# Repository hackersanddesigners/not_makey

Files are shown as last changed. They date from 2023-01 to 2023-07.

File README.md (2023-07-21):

# not_makey

This repository describes how to manufacture a shield for the ESP32, and the code to program pins as resistive touch sensors that each send strings to a laptop over Bluetooth. It is programmed to send letters that correspond with PJ machine keycodes used in e.g. this workshop https://github.com/hackersanddesigners/interfacial-workout-23

On the board you can see which pins are connected to which letter. Pins without a letter are free to use for something else (e.g. sensors, LEDs), additional code can be written inside the sketch. 

To send a letter to the laptop: 
- connect laptop to bluetooth device "NOT_MAKEY" (esp and shield should be connected to a power source)
- open a textpad on the laptop
- touch a probe connected to one of the letter pins, and a probe connected to GND to send a letter via Bluetooth

## acknowledgments

* Joylab's Jay Silver & Erik Rosenbaum's *MakeyMakey board* [https://github.com/sparkfun/MaKeyMaKey](https://github.com/sparkfun/MaKeyMaKey)
* Manualbl's [repository on using ESP32 as Bluetooth Keyboard](https://gist.github.com/manuelbl/66f059effc8a7be148adb1f104666467)
* Jack Christensen's [moving average library](https://github.com/JChristensen/movingAvg)

# v2 via Aisler board house

## bill of materials v.2 

* an ESP32 WROOM devkit, e.g. [this one from Espressif](https://www.espressif.com/en/products/modules/esp32) €14,49 at [Reichelt](https://www.reichelt.nl/nl/nl/entwicklungsboard-esp32-wroom-32e-esp32devkitc32e-p341303.html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)
* mini usb programming cable e.g. [this one at kiwi](https://www.kiwi-electronics.com/nl/microusb-kabel-usb-a-naar-micro-b-15cm-3240?search=usb-A%20naar%20micro-b) €1,25
* 4x single row break-away female header strips (you need 4x a single row strips of 15 positions) e.g. [this one](https://www.reichelt.nl/nl/nl/vrouwelijke-connector-2-54mm-1x20-scheidbaar-vertind-fis-bl1-20-z-p283794.html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) at Reichelt €1,22 each
* 14x 22Mohm resistors e.g. [this one](https://nl.farnell.com/yageo/hhv-25jt-52-22m/res-22m-5-250mw-axial-metal-film/dp/1779371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) at Farnell €0,07 each. These can be hard to find in DIY shops you might need to look at Farnell, Mouser, or get some from China :(
* 14x (or more) MM dupont jumper wires to access the pins
* alligator clips to connect connective stuff to the board. 

## schematic

The schematic is the same

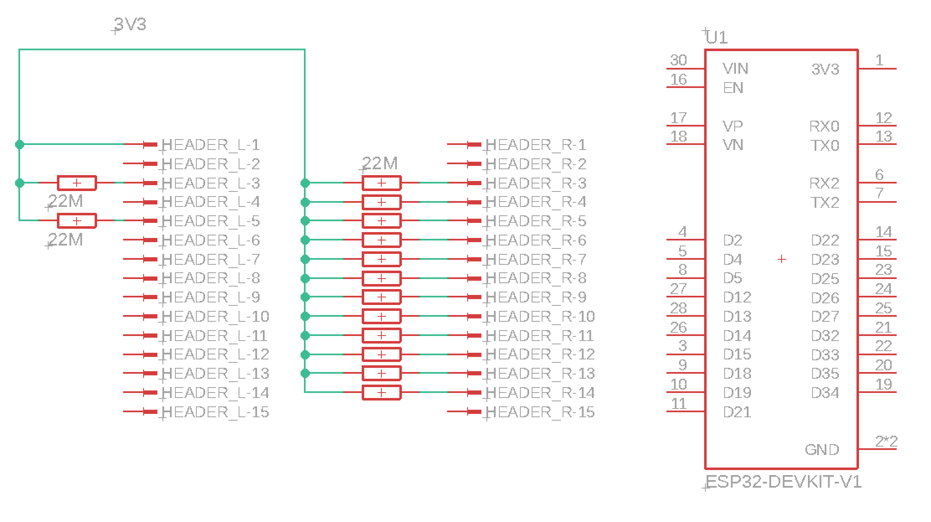
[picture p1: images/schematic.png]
schematic v2
 

## board design

The silkscreen is a bit more elaborate so you can see what character corresponds with which pin in the code.

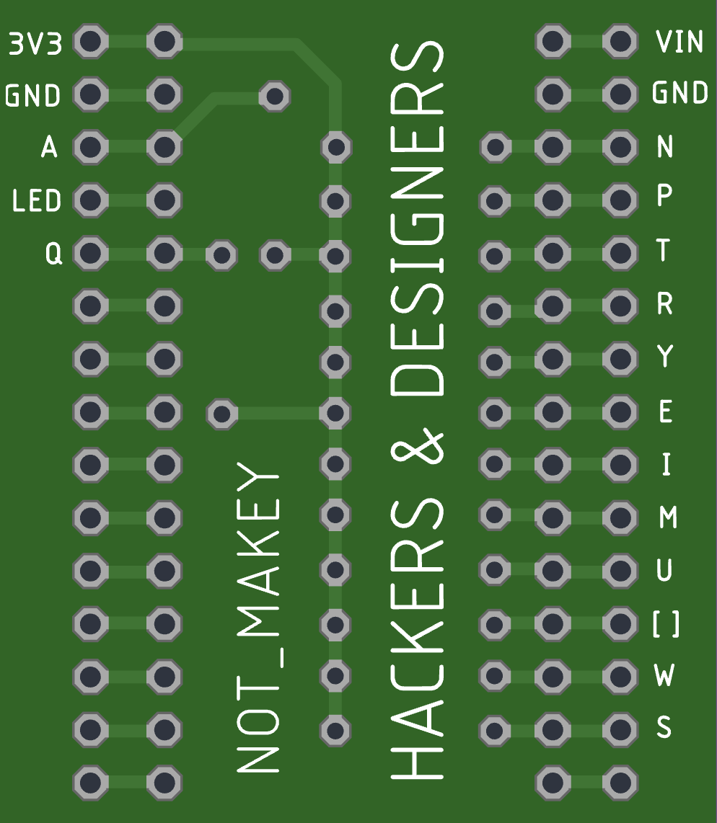
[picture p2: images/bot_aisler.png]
 

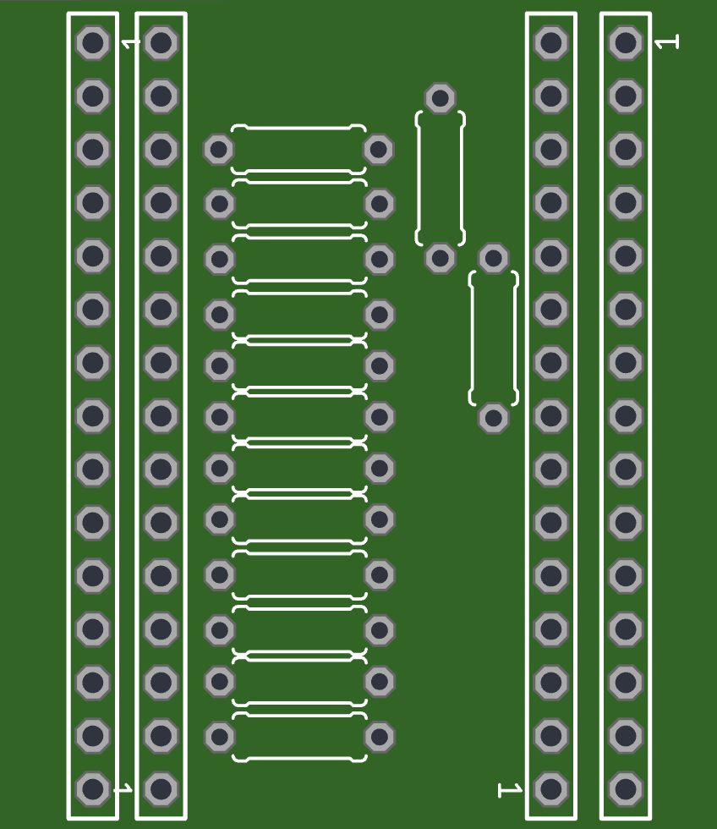
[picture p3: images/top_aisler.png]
 

## board house link

[https://aisler.net/p/JORJIJIP](https://aisler.net/p/JORJIJIP)

## soldering

For this board, you'll need to have the inner 2 connector rows facing down to connect to the ESP32 

The outer two connector rows are facing outward, to give access to the pins via jumper wires

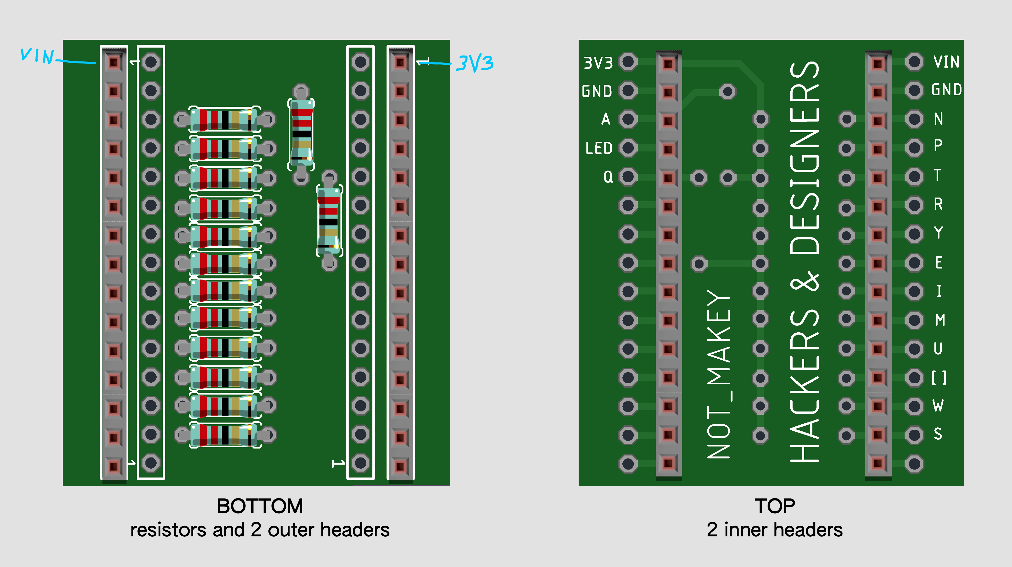
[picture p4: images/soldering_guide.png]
diagram with components in the right place


## programming the ESP

[Arduino code](./arduino/esp32_ble_makey_14probes/esp32_ble_makey_14probes.ino)

This program lets an ESP32 act as a keyboard connected via Bluetooth.
When a button attached to the ESP32 is pressed, it will generate the key strokes

In order to receive the message, add the ESP32 as a Bluetooth keyboard of your computer or mobile phone:

  1. Go to your computers/phones settings
  2. Ensure Bluetooth is turned on
  3. Scan for Bluetooth devices
  4. Connect to the device called "NOT_MAKEY" (you can change this name in the code)
  5. Open an empty document in a text editor
  6. Press the buttons attached to the ESP32 to generate different letters
 
If the probes don't respond too well you can troubleshoot and calibrate with simple code using the moving average filter and printing it to the serial. 

[Moving AVG testcode](./arduino/esp32_movingAVG_analogread/esp32_movingAVG_analogread.ino)

### Select the board

* Open Arduino preferences pane and paste the following URL in the box "Additional Boards Manager URLs"

```https://espressif.github.io/arduino-esp32/package_esp32_index.json```

* Open the Boards Manager. Go to Tools > Board > Boards Manager… 
* Search for "ESP32" and press install for "ESP32 by Espressif Systems"
* Go to > Tools > Board > ESP32 Arduino > ESP32 Devkit
* If it doesnt' show up, restart the Arduino IDE

### Compile the code to check libs are working

Compile to check if you have all the libraries. If not, check the console for troubleshooting. If necessary, install these: 

* MovingAVG library by Jack Christensen (via library manager)
* [BLE library](https://reference.arduino.cc/reference/en/libraries/esp32-ble-arduino/) (via library manger)
* [ESP32 libraries](https://github.com/espressif/arduino-esp32/tree/master/libraries) (I believe these are installed automaticallly with the ESP32 board files, so shouldn't give any problems).

### Testing 

* Connect the board to the computer with a USB data cable and upload the code
* Connect the ESP to the shield, taking care the orientation is correct. 
* Connect probes, e.g. jumper wires to one or two pins with a letter next to it
* Connect a laptop to the bluetooth device called "NOT_MAKEY" (name can be changed in line 63 in the code)
* Open a notepad on the connected laptop
* Test by touching a probe with one finger, while touching the 3V3 with the other finger. The principle is the same as makey makey, but here the resistors are connected as a pull-up resistor (keeps the signal high until a change is registered), so you touch one of the pins AND 3V3 (instead of one of the pins and GND as you would on the makey makey).

# Previous versions

## v1 via fablab

## tools

* Roland Modela MDX-20 with MODS for pcb production installed (only works in Chrome) modsproject.org

Note that this process doesn't require Gerber files, instead you need a 1000 DPI black and monochrome images of the bottom of the board, and separate files with holes and the board outline).

* Soldering station, solder, clippers

## bill of materials v.1 

* an ESP32 WROOM devkit, e.g. [this one from Espressif](https://www.espressif.com/en/products/modules/esp32) €14,49 at [Reichelt](https://www.reichelt.nl/nl/nl/entwicklungsboard-esp32-wroom-32e-esp32devkitc32e-p341303.html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)
* mini usb programming cable e.g. [this one at kiwi](https://www.kiwi-electronics.com/nl/microusb-kabel-usb-a-naar-micro-b-15cm-3240?search=usb-A%20naar%20micro-b) €1,25
* 2x single row break-away female header strips (you need 2x a single row strips of 15 positions) e.g. [this one](https://www.reichelt.nl/nl/nl/vrouwelijke-connector-2-54mm-1x20-scheidbaar-vertind-fis-bl1-20-z-p283794.html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) at Reichelt €1,22 each
* 14x 22Mohm resistors e.g. [this one](https://nl.farnell.com/yageo/hhv-25jt-52-22m/res-22m-5-250mw-axial-metal-film/dp/1779371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) at Farnell €0,07 each. These can be hard to find in DIY shops you might need to look at Farnell, Mouser, or get some from China :(
* 14 or more Alligator clips to connect your DIY buttons to the board

<img src="./images/breakaway-fem-header.png" alt="header" width="500"> 

*Break-away header strip*

## software & dependencies

* Arduino IDE: [www.arduino.cc](www.arduino.cc)
	* Install the board with the board manager: 
		* *esp32* by espressif
		* select board > ESP Arduino > ESP 32 Dev Module  
	* Install the following libraries: 
		* *movingAVG.h* by Jack Christensen
		* the other libs included in the code don't seem to need an install (perhaps come with ESP32 board definitions? > check)
* Eagle (if you want to edit or redesign the board)
* GIMP or photoshop (if you want to edit the milling files directly)

## manufacturing the shield

### prototyping setup

<img src="./images/wiring.png" alt="header" width="500"> 

### schematic v.1

<img src="./images/schematic.png" alt="header" width="600"> 

### board v.1 

<img src="./images/simple_boardlayout_bottom.png" alt="header" width="500"> 

### fabrication files for Roland modela MDX-20

####**Exporting the design from Eagle**

* exported as PNG images from Eagle at 1000 dpi in monochrome
	* MILLING - traces - exported layers: bottom, pads, via's
	* DRILLING - holes and board outline - exported layers: vias & 

####**Editing the images**

* resize images to 50% in photoshop (something happens in the export from eagle)

#####*Bottom_v1.png*

* deleted little bits and text with bucket tool
* added new text (that is not in mirror image :D) 

<img src="./fabrication/v0/bottom_v0.pnG" alt="header" width="400"> 

#####*Holes_v1.png* 

* Deleted the big 4 holes on top and bottom of the board, they're not needed but came with the footprint

<img src="./fabrication/v0/holes_v0.png" alt="header" width="400"> 

#####*Dimension_v1.png*

* manually drew a rectangle larger than the board outline to make sure the board dimension is visible in the image (otherwise it's right at the edge)

<img src="./fabrication/v0/dimension_v0.png" alt="header" width="400"> 

### milling the PCB

<img src="./fabrication/v0/modsprojectPCB_dimension.png" alt="header"> 

* Mill the [bottom.png file](./fabrication/bottom.png)
* Drill holes [cut.png file](./fabrication/cut.png)
* Mill outline [outline.png file](./fabrication/?????)
* Wash
* Test connections
* Make corrections

<img src="./images/top_milled.jpeg" alt="top, milled" width="400">

<img src="./images/bot_milled.jpeg" alt="bottom, milled" width="400"> 

### soldering

Solder resistors & connectors as per board layout

<img src="./images/soldered_bot.jpeg" alt="bottom, soldered" width="400">

<img src="./images/soldered_top.jpeg" alt="top, soldered" width="400">

## wishes based on v.1

* pads are very small, not handy. Add second row of connector pins instead? (saves space)
* bigger footprint for resistors (min .8mm drill holes, thicked pads)

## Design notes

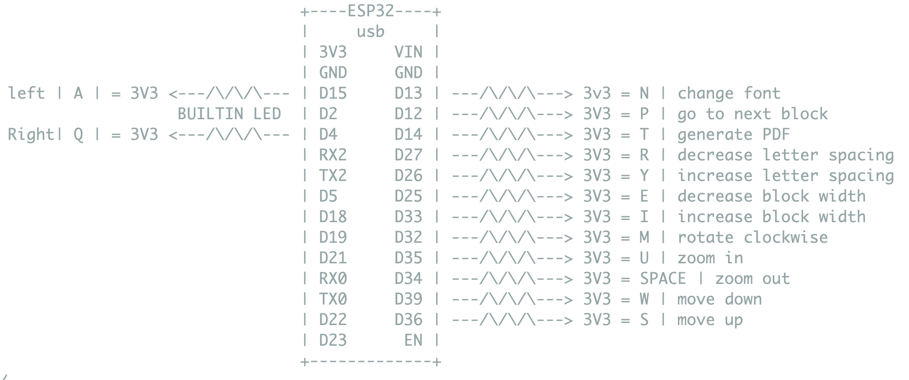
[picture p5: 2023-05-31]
images/diagram.png

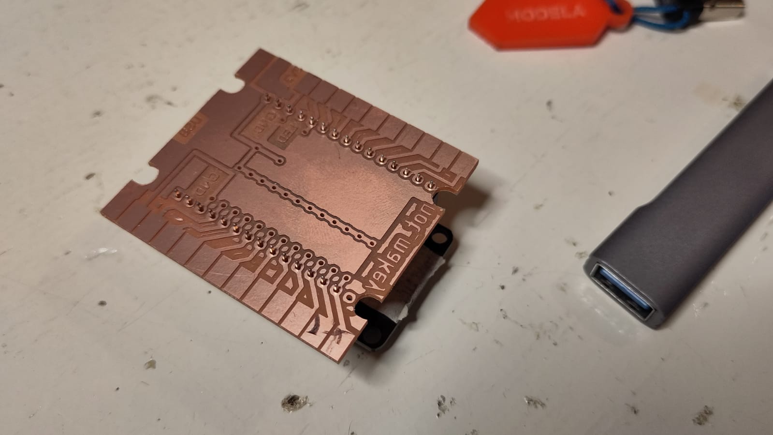
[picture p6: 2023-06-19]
images/top_milled.jpeg

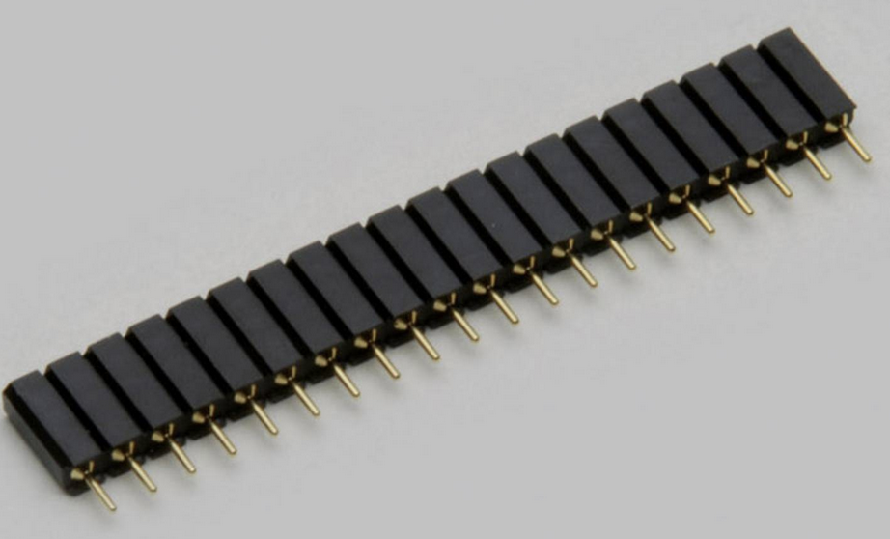
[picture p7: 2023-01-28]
images/breakaway-fem-header.png

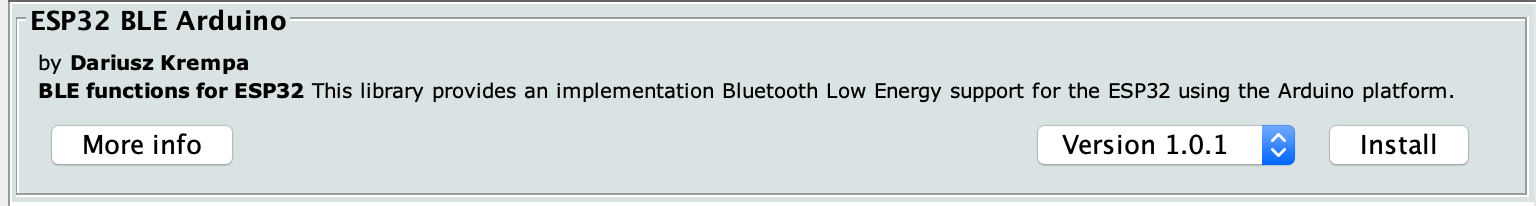
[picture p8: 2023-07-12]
images/lib-espBLE.png

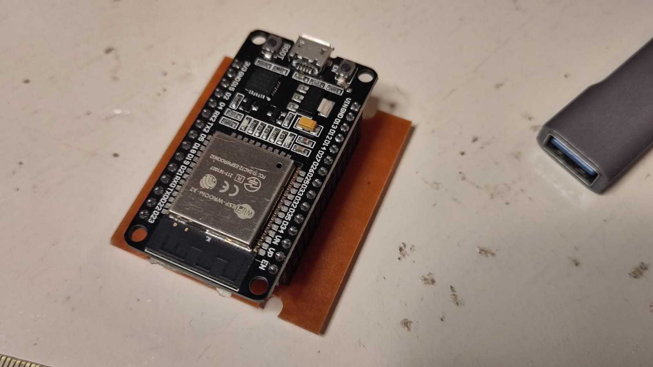
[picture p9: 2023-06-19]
images/bot_milled.jpeg

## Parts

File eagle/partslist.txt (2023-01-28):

Partlist

Exported from esp32_makey_shield.brd at 27/01/2023 16:15

EAGLE Version 9.6.2 Copyright (c) 1988-2020 Autodesk, Inc.

Assembly variant: 

Part        Value           Package                Library         Position (mil)        Orientation		Description

ADCPINS     TSW-115-07-G-S  TSW-115-XX-G-S         con-samtec      (460 918)             R90			15 pin female single row header 2.54 pitch      	
MOSTLYEMPTY TSW-115-07-G-S  TSW-115-XX-G-S         con-samtec      (1460 919)            R90			15 pin female single row header 2.54 pitch
R1          22M             0204/7                 rcl             (716 1416)            R180			22M ohm resistor (throughhole)
R2          22M             0204/7                 rcl             (716 1316)            R180			22M ohm resistor (throughhole)
R3          22M             0204/7                 rcl             (716 1216)            R180			22M ohm resistor (throughhole)
R4          22M             0204/7                 rcl             (716 1116)            R180			22M ohm resistor (throughhole)
R5          22M             0204/7                 rcl             (716 1016)            R180			22M ohm resistor (throughhole)
R6          22M             0204/7                 rcl             (716 916)             R180			22M ohm resistor (throughhole)
R7          22M             0204/7                 rcl             (716 816)             R180			22M ohm resistor (throughhole)
R8          22M             0204/7                 rcl             (716 716)             R180			22M ohm resistor (throughhole)
R9          22M             0204/7                 rcl             (716 616)             R180			22M ohm resistor (throughhole)
R10         22M             0204/7                 rcl             (716 516)             R180			22M ohm resistor (throughhole)
R11         22M             0204/7                 rcl             (716 416)             R180			22M ohm resistor (throughhole)
R12         22M             0204/7                 rcl             (716 316)             R180			22M ohm resistor (throughhole)
R13         22M             0204/7                 rcl             (1216 1416)           R0			22M ohm resistor (throughhole)
R14         22M             0204/7                 rcl             (1216 1216)           R0			22M ohm resistor (throughhole)
U1          ESP32-DEVKIT-V1 MODULE_ESP32_DEVKIT_V1 ESP32-DEVKIT-V1 (962 1014)            R0			ESP32-WROOM devkit (e.g. espressif)

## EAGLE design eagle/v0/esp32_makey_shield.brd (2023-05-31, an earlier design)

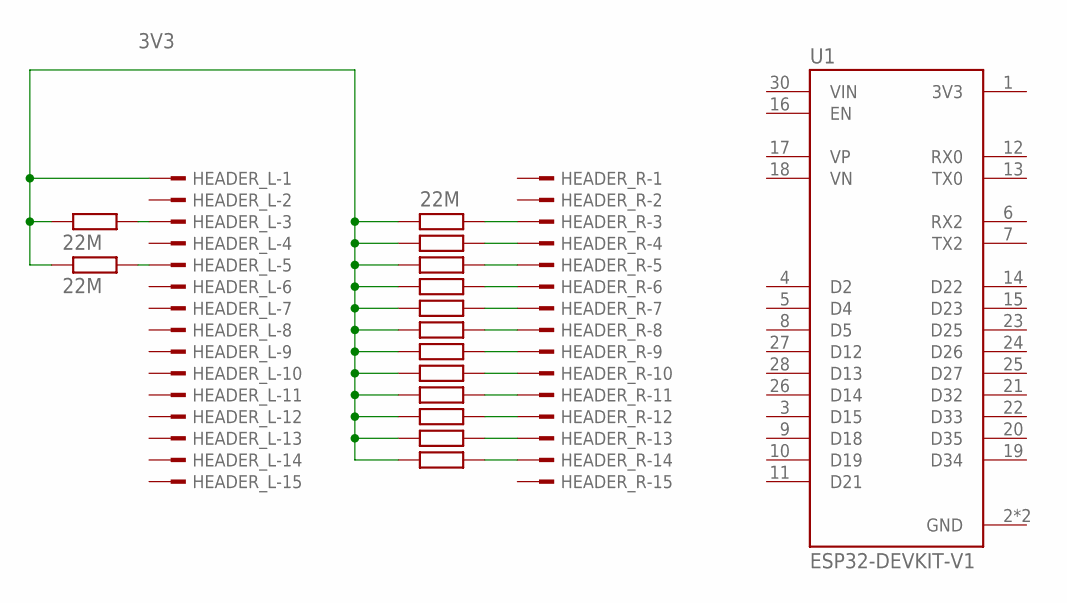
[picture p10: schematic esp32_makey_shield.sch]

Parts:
HEADER_L: TSW-115-07-G-S; TSW-115-XX-G-S
HEADER_R: TSW-115-07-G-S; TSW-115-XX-G-S
R1, R2, R3, R4, R5, R6, R7, R8, R9, R10, R11, R12, R13, R14: 22M; 0204/7
U1: ESP32-DEVKIT-V1; MODULE_ESP32_DEVKIT_V1

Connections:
3V3: HEADER_L.1, R1.1, R2.1, R3.1, R4.1, R5.1, R6.1, R7.1, R8.1, R9.1, R10.1, R11.1, R12.1, R13.1, R14.1
GND: U1.2 (GND), U1.29 (GND)
unnamed: HEADER_L.3, R13.2
unnamed: HEADER_L.5, R14.2
unnamed: HEADER_R.3, R1.2
unnamed: HEADER_R.4, R2.2
unnamed: HEADER_R.5, R3.2
unnamed: HEADER_R.6, R4.2
unnamed: HEADER_R.7, R5.2
unnamed: HEADER_R.8, R6.2
unnamed: HEADER_R.9, R7.2
unnamed: HEADER_R.10, R8.2
unnamed: HEADER_R.11, R9.2
unnamed: HEADER_R.12, R10.2
unnamed: HEADER_R.13, R11.2
unnamed: HEADER_R.14, R12.2

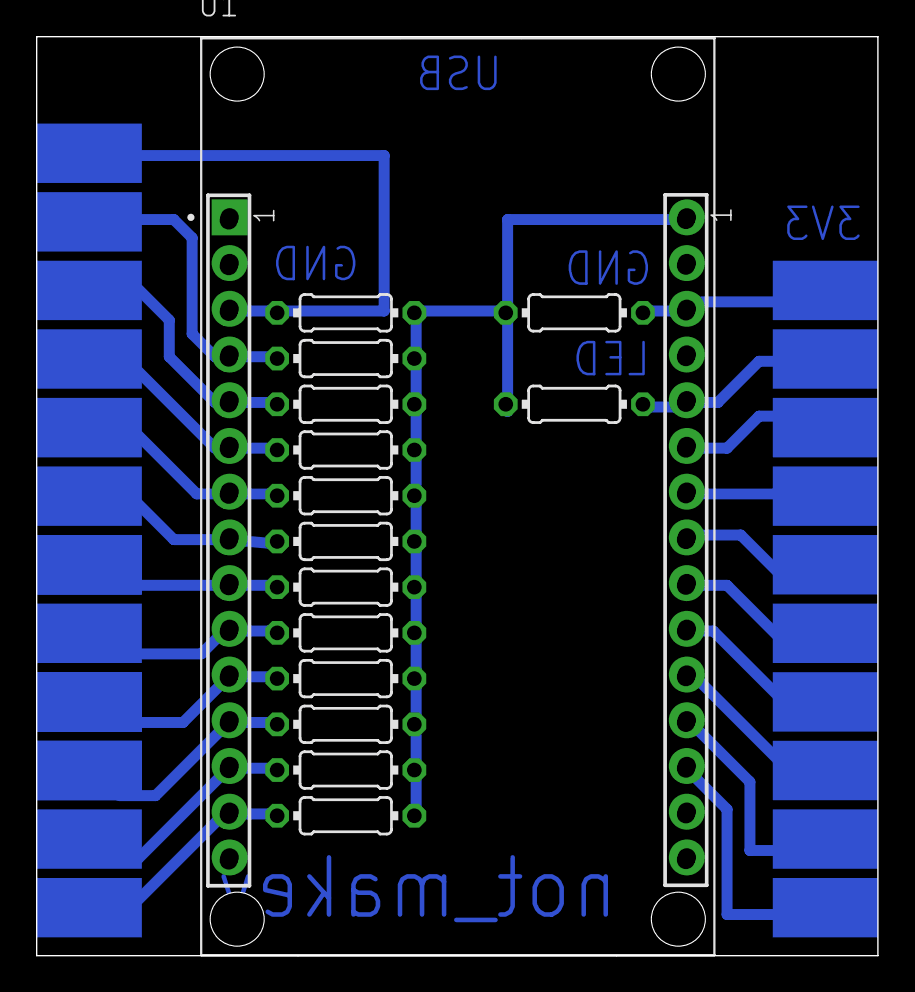
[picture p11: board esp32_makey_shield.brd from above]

Board: 2 copper layers, 46.7 x 51.1 mm, 17 parts (0 on the bottom side), 16 nets.

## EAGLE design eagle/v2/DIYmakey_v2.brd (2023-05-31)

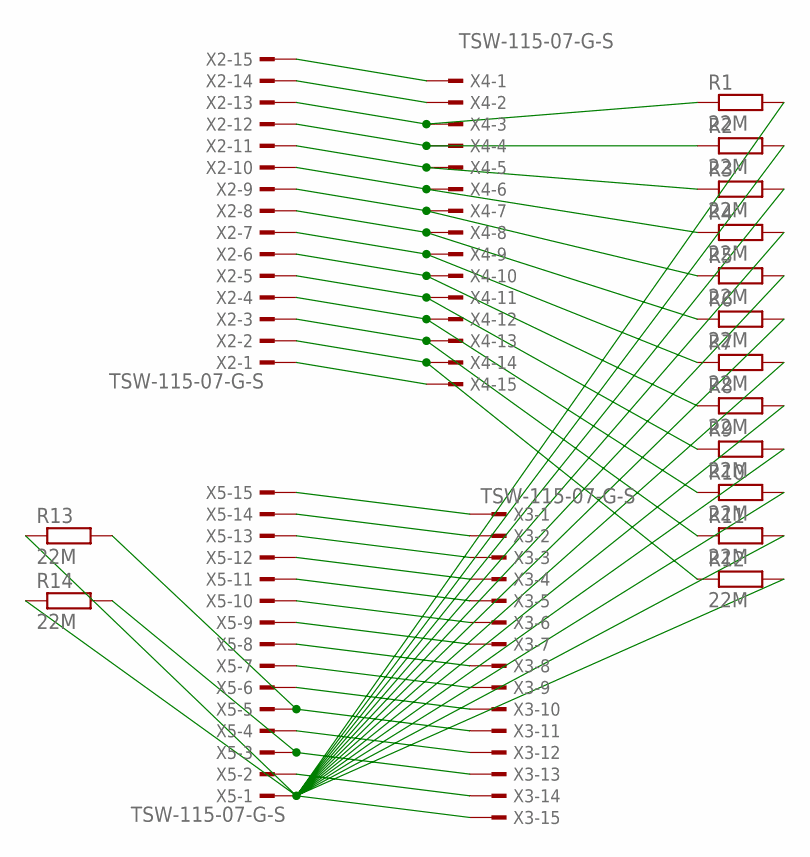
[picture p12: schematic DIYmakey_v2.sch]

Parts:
R1, R2, R3, R4, R5, R6, R7, R8, R9, R10, R11, R12, R13, R14: 22M; 0207/7
X2, X3, X4, X5: TSW-115-07-G-S; TSW-115-XX-G-S

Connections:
unnamed: X2.15, X4.1
unnamed: X2.14, X4.2
unnamed: R1.1, X2.13, X4.3
unnamed: R2.1, X2.12, X4.4
unnamed: R3.1, X2.11, X4.5
unnamed: R4.1, X2.10, X4.6
unnamed: R5.1, X2.9, X4.7
unnamed: R6.1, X2.8, X4.8
unnamed: R7.1, X2.7, X4.9
unnamed: R8.1, X2.6, X4.10
unnamed: R9.1, X2.5, X4.11
unnamed: R10.1, X2.4, X4.12
unnamed: R11.1, X2.3, X4.13
unnamed: R12.1, X2.2, X4.14
unnamed: X2.1, X4.15
unnamed: X3.1, X5.15
unnamed: X3.2, X5.14
unnamed: X3.3, X5.13
unnamed: X3.4, X5.12
unnamed: X3.5, X5.11
unnamed: X3.6, X5.10
unnamed: X3.7, X5.9
unnamed: X3.8, X5.8
unnamed: X3.9, X5.7
unnamed: X3.10, X5.6
unnamed: R13.2, X3.11, X5.5
unnamed: X3.12, X5.4
unnamed: R14.2, X3.13, X5.3
unnamed: X3.14, X5.2
unnamed: R1.2, R2.2, R3.2, R4.2, R5.2, R6.2, R7.2, R8.2, R9.2, R10.2, R11.2, R12.2, R13.1, R14.1, X3.15, X5.1

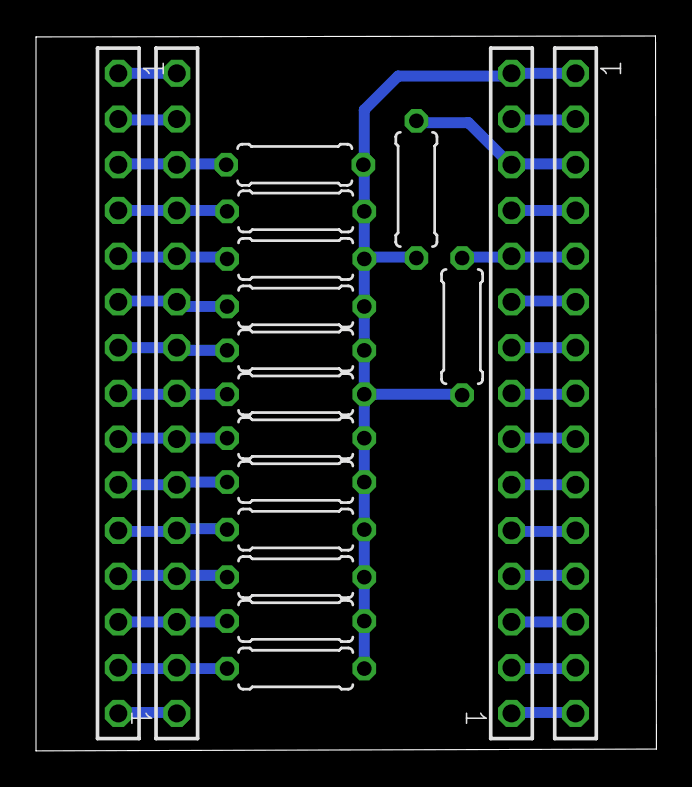
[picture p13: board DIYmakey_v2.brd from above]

Board: 2 copper layers, 34.5 x 39.7 mm, 18 parts (0 on the bottom side), 30 nets.

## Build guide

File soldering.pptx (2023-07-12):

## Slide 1

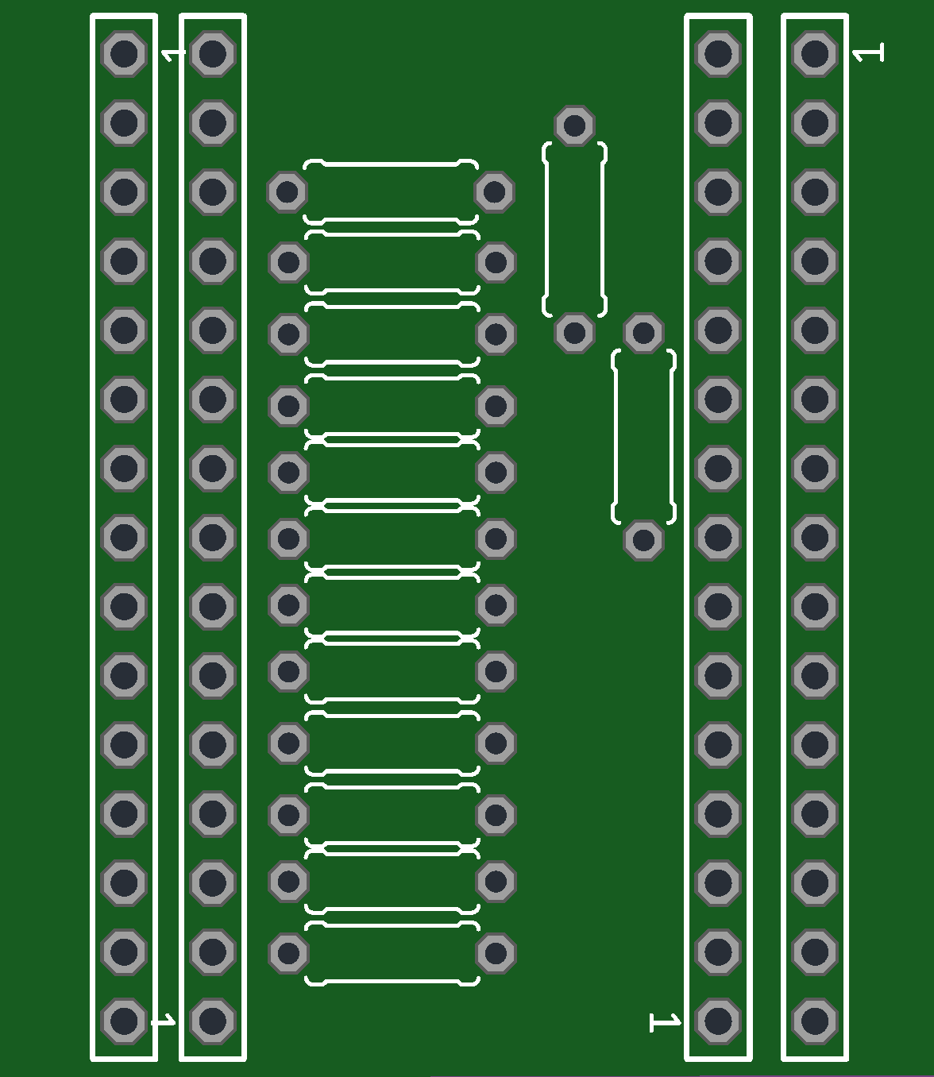
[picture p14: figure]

BOTTOM
resistors and 2 outer headers

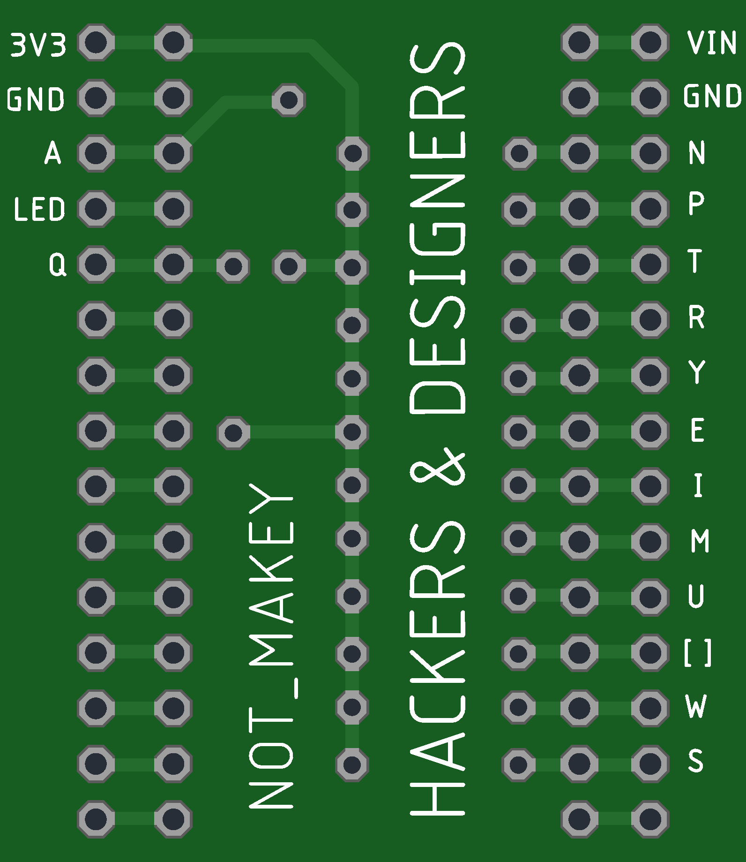
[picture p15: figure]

TOP
2 inner headers

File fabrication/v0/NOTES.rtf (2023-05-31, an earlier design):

IMAGE EXPORT
Made size too big, scale to 50%
Mods takes SVGs or PNGs (1000DPI)

The drill holes didn’t show up so I added them manually in eagle (GAH!)

>>> TO DO bcs I had to change stuff I didn’t clean up the png with the letters and so on. Bcs I put it on the bottom they’re inverse :D

BOTTOM
Layers: Bottom, Pads, Vias

DRILL/OUTLINE
Layers: Via and Dimension

MODS
In chrome: modsproject.org
Open the presets for PCB

MOUNTING BOARD
The usual, clean, double sided tape, not at the edge, press
>> measure board thickness of board and check it matches settings in mods

WEB SERIAL
Select USB port
Check connection by moving head via mods

ORIGIN
Find origin (zero is bottom left)
Use Roland MDX module > change the numbers, not arrows!
Take pic of origin

ZEROING Z
Do this manually
Move to origin
Lower the bit until it touches the copper

MILL RASTER 2D
0.4 tool diameter for traces
0.8 tool diameter for dimension and holes

CALCULATE AFTER EVERY CHANGE

CURRENT BOARD VERSION

Small holes for resistors are <.8mm so can’t calculate when that bit is selected
Instead: selected .4mm and used a .4mm milling bit instead of drill
Did one round with this bit
Then selected to .8mm to run the path with only the bigger holes

Dimension didn’t show up because it couldn’t see the thin line
Used bucket tool to make BW image with clear areas instead and deleted holes
Ran the dimension job separately

JOBS

Set PCB default module
- mill traces 1/64
- mill outline 1/32
Make sure to select the right one and check in “view tool path” module

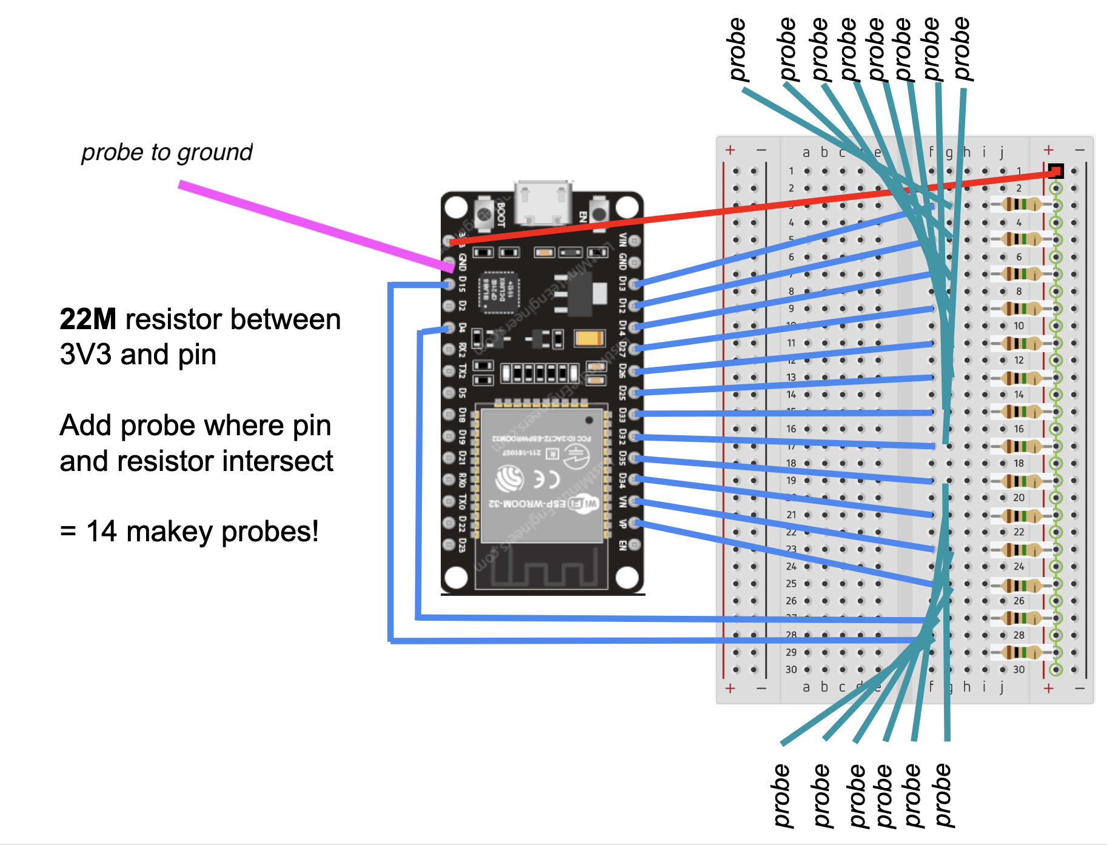
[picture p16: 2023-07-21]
images/wiring.png

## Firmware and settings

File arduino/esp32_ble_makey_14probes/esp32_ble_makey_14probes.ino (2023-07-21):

/*

  Sample program for ESP32 acting as a Bluetooth keyboard
  https://gist.github.com/manuelbl/66f059effc8a7be148adb1f104666467

  Modified by Loes (2022) To work with Sarah Garcin's PJ machine

  This program lets an ESP32 act as a keyboard connected via Bluetooth.
  When a button attached to the ESP32 is pressed, it will generate the key strokes

  In order to receive the message, add the ESP32 as a Bluetooth keyboard of your computer
  or mobile phone:

  1. Go to your computers/phones settings
  2. Ensure Bluetooth is turned on
  3. Scan for Bluetooth devices
  4. Connect to the device called "NOT_MAKEY" (you can change this name in the code)
  5. Open an empty document in a text editor
  6. Press the buttons attached to the ESP32 to generate different letters

  WIRING DIAGRAM
    14 DIY capacitive "switches" you might use with makey makey are connected to GPIO pins that have ADC
    One leg of each switch goes to a 22M pullup resistor (connect to 3V3 rail)
    The other leg of the "switch" should touch GND rail
    ADC resolution on ESP32 is 0-4095! https://randomnerdtutorials.com/esp32-adc-analog-read-arduino-ide/
    in the diagram you can see letters and correlating functions in pj machine
  /*
                                 +----ESP32----+
                                 |     usb     |
                                 | 3V3     VIN |
               White LED cathode | GND     GND | ------------> TOUCH PROBE TO GROUND
  left | A | = 3V3 <---/\/\/\--- | D15     D13 | ---/\/\/\---> 3v3 = N | change font
                    BUILTIN LED  | D2      D12 | ---/\/\/\---> 3V3 = P | go to next block
  Right| Q | = 3V3 <---/\/\/\--- | D4      D14 | ---/\/\/\---> 3V3 = T | generate PDF
                                 | RX2     D27 | ---/\/\/\---> 3V3 = R | decrease letter spacing
                                 | TX2     D26 | ---/\/\/\---> 3V3 = Y | increase letter spacing
                                 | D5      D25 | ---/\/\/\---> 3V3 = E | decrease block width
                                 | D18     D33 | ---/\/\/\---> 3V3 = I | increase block width
                                 | D19     D32 | ---/\/\/\---> 3V3 = M | rotate clockwise
                                 | D21     D35 | ---/\/\/\---> 3V3 = U | zoom in
                                 | RX0     D34 | ---/\/\/\---> 3V3 = SPACE | zoom out
                                 | TX0     D39 | ---/\/\/\---> 3V3 = W | move down
                                 | D22     D36 | ---/\/\/\---> 3V3 = S | move up
                 White LED anode | D23      EN |
                                 +-------------+
*/


#define US_KEYBOARD 1

#include <Arduino.h>
#include "BLEDevice.h"
#include "BLEHIDDevice.h"
#include "HIDKeyboardTypes.h"
#include <movingAvg.h>

// Define values that constitute Pressed and Released (find values w other sketch)
const int PressedMaxThreshold = 2400;
const int ReleasedMinThreshold = 2700;

const byte PinCount = 14;

// how esp shows up in bluetooth device list
#define DEVICE_NAME "NOT_YOUR_MAKEY"

// array w numbers of all 14 pins with ADC (pin2 doesnt work w BLE)
const byte InputPins[PinCount] = {15, 4, 13, 12, 14, 27, 26, 25, 33, 32, 35, 34, 39, 36}; // ONLY ADC PINS!
int buttonState[] = {0, 0, 0, 0, 0, 0, 0, 0, 0, 0, 0, 0, 0, 0};
int prevButtonState[] = {LOW, LOW, LOW, LOW, LOW, LOW, LOW, LOW, LOW, LOW, LOW, LOW, LOW, LOW};
const char KeyCodes[PinCount] = {'a', 'q', 'n', 'p', 't', 'r', 'y', 'e', 'i', 'm', 'u', ' ', 'w', 's'};

const int ledPin =  23
;      // builtin LED on esp32
int delayTime = 100;

struct TouchInput {
  byte analogPin;
  char keycode;
  movingAvg filter = movingAvg(20);     // use moving average filter that takes 20 samples
  boolean wasPressed = false;
};

TouchInput Pins[PinCount];

// Forward declarations
void bluetoothTask(void*);
void typeText(const char* text);

bool isBleConnected = false;

// define 14 keystrokes used in PJ machine
#define MESSAGE0 "a\n"
#define MESSAGE1 "q\n"
#define MESSAGE2 "n\n"
#define MESSAGE3 "p\n"
#define MESSAGE4 "t\n"
#define MESSAGE5 "r\n"
#define MESSAGE6 "y\n"
#define MESSAGE7 "e\n"
#define MESSAGE8 "i\n"
#define MESSAGE9 "m\n"
#define MESSAGE10 "u\n"
#define MESSAGE11 " \n"
#define MESSAGE12 "w\n"
#define MESSAGE13 "s\n"

void setup() {
  Serial.begin(115200);

  // configure pins for all buttons by cycling through array
  for (int thisPin = 0; thisPin < PinCount; thisPin++) {
    Pins[thisPin].analogPin = InputPins[thisPin];
    Pins[thisPin].keycode = KeyCodes[thisPin];
    Pins[thisPin].filter.begin();
  }

  //configure built in led (ESP32 has this on pin 2) as output
  pinMode(ledPin, OUTPUT);

  // start Bluetooth task
  xTaskCreate(bluetoothTask, "bluetooth", 20000, NULL, 5, NULL);
}


// Define Output Actions
int outputAction(int currentButton) {
  if (currentButton == 0) {
    typeText(MESSAGE0);
    digitalWrite(ledPin, HIGH);
    delay(delayTime);
  }
  if (currentButton == 1) {
    typeText(MESSAGE1);
    digitalWrite(ledPin, HIGH);
    delay(delayTime);
  }
  if (currentButton == 2) {
    typeText(MESSAGE2);
    digitalWrite(ledPin, HIGH);
    delay(delayTime);
  }
  if (currentButton == 3) {
    typeText(MESSAGE3);
    digitalWrite(ledPin, HIGH);
    delay(delayTime);
  }
  if (currentButton == 4) {
    typeText(MESSAGE4);
    digitalWrite(ledPin, HIGH);
    delay(delayTime);
  }
  if (currentButton == 5) {
    typeText(MESSAGE5);
    digitalWrite(ledPin, HIGH);
    delay(delayTime);
  }
  if (currentButton == 6) {
    typeText(MESSAGE6);
    digitalWrite(ledPin, HIGH);
    delay(delayTime);
  }
  if (currentButton == 7) {
    typeText(MESSAGE7);
    digitalWrite(ledPin, HIGH);
    delay(delayTime);
  }
  if (currentButton == 8) {
    typeText(MESSAGE8);
    digitalWrite(ledPin, HIGH);
    delay(delayTime);
  }
  if (currentButton == 9) {
    typeText(MESSAGE9);
    digitalWrite(ledPin, HIGH);
    delay(delayTime);
  }
  if (currentButton == 10) {
    typeText(MESSAGE10);
    digitalWrite(ledPin, HIGH);
    delay(delayTime);
  }
  if (currentButton == 11) {
    typeText(MESSAGE11);
    digitalWrite(ledPin, HIGH);
    delay(delayTime);
  }
  if (currentButton == 12) {
    typeText(MESSAGE12);
    digitalWrite(ledPin, HIGH);
    delay(delayTime);
  }
  if (currentButton == 13) {
    typeText(MESSAGE13);
    digitalWrite(ledPin, HIGH);
    delay(delayTime);
  }

  digitalWrite(ledPin, LOW);
  delay(10);
}


void loop() {

  if (isBleConnected) {
    for (int thisPin = 0; thisPin < PinCount; thisPin++) {
      float currentAverage = Pins[thisPin].filter.reading(analogRead(Pins[thisPin].analogPin));
      Serial.println(currentAverage);
      boolean previousState = Pins[thisPin].wasPressed;
      boolean currentState = previousState; // Default if in the dead zone
      if (currentAverage < PressedMaxThreshold) {
        currentState = true;      // Pressed
      }
      else if (currentAverage > ReleasedMinThreshold) {
        currentState = false;      // Released
      }
      if (currentState != previousState) {
        if (currentState) {
          outputAction(thisPin);
        }
        Pins[thisPin].wasPressed = currentState;
      }
    }
  }
}

// Message (report) sent when a key is pressed or released
struct InputReport {
  uint8_t modifiers;       // bitmask: CTRL = 1, SHIFT = 2, ALT = 4
  uint8_t reserved;        // must be 0
  uint8_t pressedKeys[6];  // up to six concurrenlty pressed keys
};

// Message (report) received when an LED's state changed
struct OutputReport {
  uint8_t leds;            // bitmask: num lock = 1, caps lock = 2, scroll lock = 4, compose = 8, kana = 16
};


// The report map describes the HID device (a keyboard in this case) and
// the messages (reports in HID terms) sent and received.
static const uint8_t REPORT_MAP[] = {
  USAGE_PAGE(1),      0x01,       // Generic Desktop Controls
  USAGE(1),           0x06,       // Keyboard
  COLLECTION(1),      0x01,       // Application
  REPORT_ID(1),       0x01,       //   Report ID (1)
  USAGE_PAGE(1),      0x07,       //   Keyboard/Keypad
  USAGE_MINIMUM(1),   0xE0,       //   Keyboard Left Control
  USAGE_MAXIMUM(1),   0xE7,       //   Keyboard Right Control
  LOGICAL_MINIMUM(1), 0x00,       //   Each bit is either 0 or 1
  LOGICAL_MAXIMUM(1), 0x01,
  REPORT_COUNT(1),    0x08,       //   8 bits for the modifier keys
  REPORT_SIZE(1),     0x01,
  HIDINPUT(1),        0x02,       //   Data, Var, Abs
  REPORT_COUNT(1),    0x01,       //   1 byte (unused)
  REPORT_SIZE(1),     0x08,
  HIDINPUT(1),        0x01,       //   Const, Array, Abs
  REPORT_COUNT(1),    0x06,       //   6 bytes (for up to 6 concurrently pressed keys)
  REPORT_SIZE(1),     0x08,
  LOGICAL_MINIMUM(1), 0x00,
  LOGICAL_MAXIMUM(1), 0x65,       //   101 keys
  USAGE_MINIMUM(1),   0x00,
  USAGE_MAXIMUM(1),   0x65,
  HIDINPUT(1),        0x00,       //   Data, Array, Abs
  REPORT_COUNT(1),    0x05,       //   5 bits (Num lock, Caps lock, Scroll lock, Compose, Kana)
  REPORT_SIZE(1),     0x01,
  USAGE_PAGE(1),      0x08,       //   LEDs
  USAGE_MINIMUM(1),   0x01,       //   Num Lock
  USAGE_MAXIMUM(1),   0x05,       //   Kana
  LOGICAL_MINIMUM(1), 0x00,
  LOGICAL_MAXIMUM(1), 0x01,
  HIDOUTPUT(1),       0x02,       //   Data, Var, Abs
  REPORT_COUNT(1),    0x01,       //   3 bits (Padding)
  REPORT_SIZE(1),     0x03,
  HIDOUTPUT(1),       0x01,       //   Const, Array, Abs
  END_COLLECTION(0)               // End application collection
};


BLEHIDDevice* hid;
BLECharacteristic* input;
BLECharacteristic* output;

const InputReport NO_KEY_PRESSED = { };


/*
   Callbacks related to BLE connection
*/
class BleKeyboardCallbacks : public BLEServerCallbacks {

    void onConnect(BLEServer* server) {
      isBleConnected = true;

      // Allow notifications for characteristics
      BLE2902* cccDesc = (BLE2902*)input->getDescriptorByUUID(BLEUUID((uint16_t)0x2902));
      cccDesc->setNotifications(true);

      Serial.println("Client has connected");
    }

    void onDisconnect(BLEServer* server) {
      isBleConnected = false;

      // Disallow notifications for characteristics
      BLE2902* cccDesc = (BLE2902*)input->getDescriptorByUUID(BLEUUID((uint16_t)0x2902));
      cccDesc->setNotifications(false);

      Serial.println("Client has disconnected");
    }
};


/*
   Called when the client (computer, smart phone) wants to turn on or off
   the LEDs in the keyboard.

   bit 0 - NUM LOCK
   bit 1 - CAPS LOCK
   bit 2 - SCROLL LOCK
*/
class OutputCallbacks : public BLECharacteristicCallbacks {
    void onWrite(BLECharacteristic* characteristic) {
      OutputReport* report = (OutputReport*) characteristic->getData();
      Serial.print("LED state: ");
      Serial.print((int) report->leds);
      Serial.println();
    }
};


void bluetoothTask(void*) {

  // initialize the device
  BLEDevice::init(DEVICE_NAME);
  BLEServer* server = BLEDevice::createServer();
  server->setCallbacks(new BleKeyboardCallbacks());

  // create an HID device
  hid = new BLEHIDDevice(server);
  input = hid->inputReport(1); // report ID
  output = hid->outputReport(1); // report ID
  output->setCallbacks(new OutputCallbacks());

  // set manufacturer name
  hid->manufacturer()->setValue("Maker Community");
  // set USB vendor and product ID
  hid->pnp(0x02, 0xe502, 0xa111, 0x0210);
  // information about HID device: device is not localized, device can be connected
  hid->hidInfo(0x00, 0x02);

  // Security: device requires bonding
  BLESecurity* security = new BLESecurity();
  security->setAuthenticationMode(ESP_LE_AUTH_BOND);

  // set report map
  hid->reportMap((uint8_t*)REPORT_MAP, sizeof(REPORT_MAP));
  hid->startServices();

  // set battery level to 100%
  hid->setBatteryLevel(100);

  // advertise the services
  BLEAdvertising* advertising = server->getAdvertising();
  advertising->setAppearance(HID_KEYBOARD);
  advertising->addServiceUUID(hid->hidService()->getUUID());
  advertising->addServiceUUID(hid->deviceInfo()->getUUID());
  advertising->addServiceUUID(hid->batteryService()->getUUID());
  advertising->start();

  Serial.println("BLE ready");
  delay(portMAX_DELAY);
};


void typeText(const char* text) {
  int len = strlen(text);
  for (int i = 0; i < len; i++) {

    // translate character to key combination
    uint8_t val = (uint8_t)text[i];
    if (val > KEYMAP_SIZE)
      continue; // character not available on keyboard - skip
    KEYMAP map = keymap[val];

    // create input report
    InputReport report = {
      .modifiers = map.modifier,
      .reserved = 0,
      .pressedKeys = {
        map.usage,
        0, 0, 0, 0, 0
      }
    };

    // send the input report
    input->setValue((uint8_t*)&report, sizeof(report));
    input->notify();

    delay(5);

    // release all keys between two characters; otherwise two identical
    // consecutive characters are treated as just one key press
    input->setValue((uint8_t*)&NO_KEY_PRESSED, sizeof(NO_KEY_PRESSED));
    input->notify();

    delay(5);
  }
}

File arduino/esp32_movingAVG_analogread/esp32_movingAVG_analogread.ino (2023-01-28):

// Arduino Moving Average Library
// https://github.com/JChristensen/movingAvg
// Copyright (C) 2018 by Jack Christensen and licensed under
// GNU GPL v3.0, https://www.gnu.org/licenses/gpl.html
//
// Example sketch to smooth the readings from a CdS photocell.
// Connect the photocell from the A0 pin to ground. The internal pullup
// resistor is used to form a voltage divider. A potentiometer or
// something similar could be used in place of a photocell.

#include <movingAvg.h>                  // https://github.com/JChristensen/movingAvg

const uint8_t PHOTOCELL_PIN(15);        // connect photocell from A0 pin to ground
movingAvg photoCell(20);                // define the moving average object

void setup()
{
    pinMode(PHOTOCELL_PIN, INPUT);
    Serial.begin(115200);
    photoCell.begin();
}

void loop()
{
    int pc = analogRead(PHOTOCELL_PIN); // read the photocell
    int avg = photoCell.reading(pc);    // calculate the moving average
    Serial.print(pc);                   // print the individual reading
    Serial.print(' ');
    Serial.println(avg);                // print the moving average
    delay(20);
}

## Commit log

2023-05-31 add v2 ready for aisler fabrication
    [DIYmakey_v2.brd, DIYmakey_v2.sch, esp32_makey_shield.brd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]
2023-07-12 add code and soldering documentation
2023-07-12 add workdoc for soldering in case mistakes
2023-07-21 fix GND probe update wiring
    [esp32_ble_makey_14probes.ino]
